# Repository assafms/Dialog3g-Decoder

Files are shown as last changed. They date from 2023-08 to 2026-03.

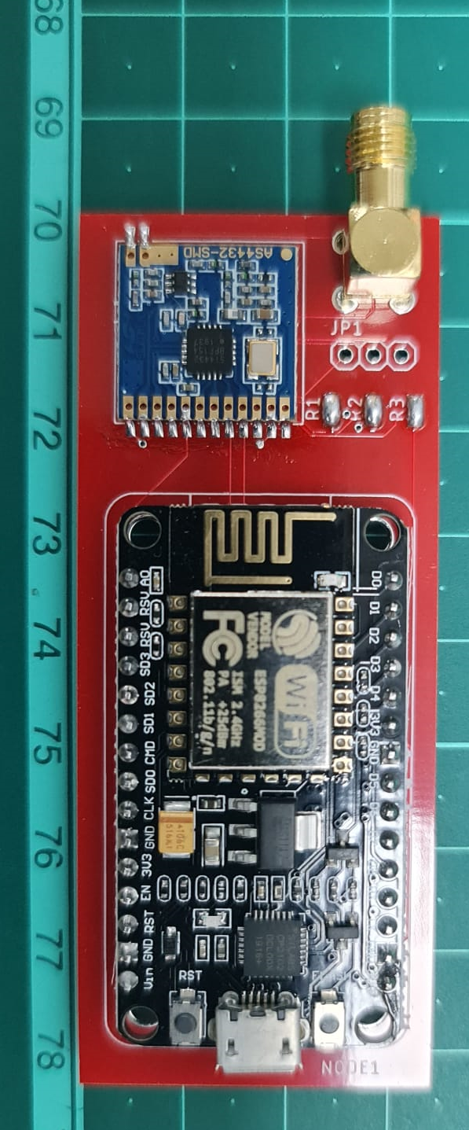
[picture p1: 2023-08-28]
PCB/completed board.png

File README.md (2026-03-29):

# Arad Dialog 3G Water Meter Decoder

ESPHome custom component and PCB for reading Arad Dialog 3G water meters using an SI4432 (XL4432) RF module and an ESP8266/ESP32.

## Overview

The Arad Dialog 3G is a water meter deployed in Israel and other countries operating at 916.3 MHz (868 MHz in some regions). This project provides:

- **Custom PCB** connecting an XL4432 module to an ESP via SPI
- **ESPHome component** that receives and decodes meter packets
- **Unified LFSR validation** for all meter groups — single model, no per-group configuration
- **3-bit error correction** — recovers packets with up to 3 corrupted bits
- **ID recovery** — corrects corrupted meter IDs using per-meter constants from validated packets

## Meter Groups

| Group | Bytes 8-9 | Cons Divisor | Notes |
|---|---|---|---|
| Standard | `0x00 0x00` | ÷10 (0.1 m³) | Residential meters |
| Sonata/x40 | `0x00 0x40` | ÷1000 (1 liter) | Commercial/street meters |
| 3D0C | `0x3D 0x0C` | ÷10 (0.1 m³) | Older model |

All groups use the same unified LFSR model with a single universal offset (`0x6FF11521E8`). No per-group detection or configuration needed — bytes 8-9 are just more data bits in the LFSR.

## How It Works

The meter transmits a 21-byte FSK/Manchester-encoded packet every ~30 seconds containing the meter ID and consumption reading. The ESPHome component validates every packet using a unified LFSR-based GF(2) model that works for all meter groups. It also applies up to 3-bit error correction to recover packets with minor RF corruption. Only validated readings are published to Home Assistant.

## Hardware

| Component | Approximate Cost |
|---|---|
| ESP8266 or ESP32 | ~$4 |
| XL4432 / SI4432 RF module | ~$2 |
| Custom PCB (see `PCB/`) or manual SPI wiring | ~$0.50 |

See `PCB/` for Eagle source files, Gerber outputs, and board photos.

## RF Parameters

| Parameter | Value |
|---|---|
| Frequency | 916.3 MHz |
| Modulation | FSK |
| Encoding | Manchester (IEEE 802.3) |
| Data Rate | 59.45 kbps |
| Frequency Deviation | 175 kHz |
| Receiver Bandwidth | 600 kHz |
| Transmission Interval | ~30 seconds |
| Preamble | 7 nibbles |
| Sync Word | `0x3E 0x69` |
| Payload | 21 bytes, fixed length, no CRC |

## Quick Start

1. Build the PCB or wire the XL4432 to the ESP via SPI (see `esphome/README.md` for pinout)
2. Copy `esphome/custom_components/xl4432_spi_sensor/` to your ESPHome `custom_components/` directory
3. Add to your YAML:

```yaml
sensor:
  - platform: xl4432_spi_sensor
    name: water_meter
    cs_pin: GPIO15
    meter_id: "0x4E61BC"
    accuracy_decimals: 1
```

4. Find your meter ID: read the decimal serial number on the meter, convert to hex. Example: decimal `5136830` → hex `0x4E61BE`. The packet transmits this big-endian.

## Packet Sniffer Mode

To capture raw packets from all nearby meters:

```yaml
sensor:
  - platform: xl4432_spi_sensor
    name: sniffer
    cs_pin: GPIO15
    meter_id: "0x000000"
    packet_sniff: true
```

All received packets are logged at INFO level. No validation or filtering is performed.

## Wireless Connection

Add `tcp_server: true` to stream packets over WiFi to the Android collector app instead of USB:

```yaml
sensor:
  - platform: xl4432_spi_sensor
    name: sniffer
    cs_pin: GPIO15
    meter_id: "0x000000"
    packet_sniff: true
    tcp_server: true
```

Enable phone hotspot, configure ESPHome WiFi with the hotspot credentials, and the Android app auto-discovers the ESP on port 4321.

## Packet Structure

| Byte(s) | Field | Description |
|---|---|---|
| 0-1 | Header | Static (`0x0A 0xEC`) |
| 2-4 | Type | Meter type / firmware variant |
| 5-7 | Meter ID | 3 bytes, big-endian |
| 8-9 | Group | `0x00 0x00` standard, `0x00 0x40` x40, `0x3D 0x0C` 3D0C |
| 10-12 | Consumption | 3 bytes, little-endian. STD/3D0C: ÷10 for m³. Sonata/x40: ÷1000 for m³ |
| 13-14 | Status | Usually `0x00 0x05` |
| 15-19 | Scramble | GF(2) integrity field |
| 20 | Trailer | High nibble only (low nibble unreliable due to Manchester timing drift) |

## GF(2) Scrambling Algorithm

Bytes 15-19 of each packet contain a 40-bit value that is a **linear function over GF(2)** of all data bytes 0-14, computed via a single 40-bit LFSR:

```
scrambled = OFFSET ^ ⨁(LFSR_vec[pos] for each set bit in bytes 0-14)
```

Where:
- **OFFSET** = `0x6FF11521E8` — universal, same for all meter groups
- All 120 basis vectors are consecutive states of a 40-bit LFSR (seed `0x51AAF3D980`, 3 feedback taps)
- Forward chain: bytes 12→11→10→9→8→7→6→5→4→3→2→1→0 (104 states)
- Backward chain: bytes 13→14 (16 states, stored as lookup)
- **^** is bitwise XOR

### Validation

Single model for all groups: compute expected scramble via LFSR from bytes 0-14, compare to received bytes 15-19. Up to 3 corrupted bits can be automatically corrected using 160 syndrome bits (120 data + 40 scramble). Achieves 80% STD, 78% x40, 83% 3D0C validation rate. See `PROTOCOL.md` for full details and basis vector tables.

## Links

- [Dialog3g-Decoder-research](https://github.com/assafms/Dialog3g-Decoder-research) — Research repo with analysis scripts, Android collector app, and detailed protocol documentation
- [rtl_433 Protocol 260](https://github.com/merbanan/rtl_433) — SDR-based decoder
- [rtl_433 Issue #1992](https://github.com/merbanan/rtl_433/issues/1992) — Original protocol analysis
- [rtl_433 Discussion #3414](https://github.com/merbanan/rtl_433/discussions/3414) — Arad Sonata analysis

## License

This project is the result of independent reverse engineering for research and interoperability purposes. Not affiliated with Arad Ltd.

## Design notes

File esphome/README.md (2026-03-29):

# ESPHome Dialog 3G Component

Custom ESPHome component for receiving and validating Arad Dialog 3G water meter transmissions using an XL4432/SI4432 RF module.

## Features

- Unified LFSR validation with up to 3-bit error correction — all meter groups, single model
- Configurable meter ID via YAML
- Packet sniffer mode for discovering meters and debugging
- Automatic low-nibble masking on byte 20 (unreliable due to Manchester timing drift)

## Installation

Copy `custom_components/xl4432_spi_sensor/` to your ESPHome config directory:

```
config/
  your_device.yaml
  custom_components/
    xl4432_spi_sensor/
      __init__.py
      sensor.py
      xl4432.cpp
      xl4432.h
      xl4432_spi_sensor.cpp
      xl4432_spi_sensor.h
```

## Configuration

```yaml
sensor:
  - platform: xl4432_spi_sensor
    name: water_meter
    cs_pin: GPIO15
    meter_id: "0x4E61BC"
    accuracy_decimals: 1
```

### Options

| Option | Required | Default | Description |
|---|---|---|---|
| `meter_id` | Yes | — | Meter ID as hex string (e.g., `"0x4E61BC"`) |
| `cs_pin` | Yes | — | SPI chip select pin |
| `packet_sniff` | No | `false` | Log all packets without filtering or publishing |
| `tcp_server` | No | `false` | Stream packets over WiFi (TCP port 4321) for the Android app |
| `accuracy_decimals` | No | `1` | Decimal places for the consumption reading |

### Finding Your Meter ID

1. Read the decimal serial number printed on the meter
2. Convert to hexadecimal
3. Reverse the byte order
4. Use in YAML config

Example: decimal `5136830` -> hex `0x4E61BE` -> reversed `0xBE614E` -> `meter_id: "0xBE614E"`

## How Validation Works

Bytes 15-19 of each packet contain a 40-bit scrambled value computed via a unified LFSR-based GF(2) linear function of all data bytes 0-14. The component computes the expected scramble and compares it to the received value. If they don't match, it attempts to correct up to 3 bit errors using syndrome matching across 160 bit positions.

- **Valid**: expected scramble matches — reading is published to Home Assistant
- **Corrected (1-3 bits)**: bit errors detected and fixed — corrected reading is published
- **Invalid**: more than 3 bit errors — packet is discarded (logged as warning)
- **ID mismatch**: packet is from a different meter — silently ignored

Works for all meter groups (STD, x40/Sonata, 3D0C) with a single universal offset. No per-group configuration needed.

## Packet Sniffer Mode

Set `packet_sniff: true` to log all received packets at INFO level without filtering or validation. Useful for:

- Discovering nearby meter IDs
- Collecting packet data for analysis
- Debugging RF reception

## Wireless Connection (TCP Server)

Set `tcp_server: true` to stream all received packets over WiFi to the Android collector app — no USB cable needed.

```yaml
sensor:
  - platform: xl4432_spi_sensor
    name: water_meter
    cs_pin: GPIO15
    meter_id: "0x93D9E9"
    packet_sniff: true
    tcp_server: true
```

Setup:
1. Enable phone hotspot
2. Configure ESPHome WiFi with the hotspot SSID and password
3. Power on the ESP — it connects to the hotspot
4. Open the Android app — it auto-discovers the ESP on port 4321

The TCP server streams packets in the same format as the serial log, so both USB and WiFi connections work with the same app.

## SPI Wiring

| ESP Pin | XL4432 Pin | Function |
|---|---|---|
| GPIO14 | SCK | SPI Clock |
| GPIO13 | SDI | SPI MOSI |
| GPIO12 | SDO | SPI MISO |
| GPIO15 | nSEL | Chip Select |
| GPIO5 | nIRQ | Interrupt |

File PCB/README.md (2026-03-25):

# PCB Design

Custom PCB connecting an XL4432 (SI4432) RF module to an ESP8266/ESP32 via SPI.

## Contents

| Directory | Description |
|---|---|
| `Eagle/` | Source schematic and board files (Eagle CAD) |
| `Gerber/` | Production-ready Gerber files (PCBWay compatible) |

## Assembly Notes

- **R1, R2, R3**: Use 0-ohm resistors or solder bridges (short the pads)
- See `schematic.png` and `pcb.png` for reference
- `completed board.png` shows an assembled example

## Bill of Materials

See `Eagle/BOM` for the full component list.

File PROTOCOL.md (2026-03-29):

# Arad Dialog 3G Water Meter — RF Protocol Reference

Reverse-engineered protocol documentation for the Arad Dialog 3G water meter (Israeli version).

> **Disclaimer**: This protocol is proprietary to Arad Ltd. This document is the result of independent reverse engineering for research and interoperability purposes. Not affiliated with Arad.

---

## 1. RF / Physical Layer

| Parameter | Value |
|---|---|
| Frequency | 916.3 MHz |
| Modulation | FSK |
| Encoding | Manchester (zero-bit variant, IEEE 802.3) |
| Data Rate | 59.45 kbps |
| Frequency Deviation  | 175 kHz |
| Receiver Bandwidth | 600 kHz |
| Transmission Interval| ~30 seconds |
| Preamble | 7 nibbles, pattern `01010` |
| Sync Word | `0x3E 0x69` |
| Payload | 21 bytes, fixed length, no CRC |

---

## 2. Packet Layout

| Byte  | Field | Notes |
|---|---|---|
| 0–1 | Static header | Always `0x0A 0xEC` |
| 2 | Header variant | Usually `0x7A`. `0x6A` seen on some meters |
| 3 | Type byte | Always `0xC8` |
| 4 | **Status / type** | `0x4B` normal. Bit 5 (`0x20`) = general alarm. Bit 7 (`0x80`) = reboot (consumption invalid). **Bit 5 feeds into scramble** |
| 5–7 | **Meter ID** | 3 bytes, big-endian (see below) |
| 8–9 | Meter group | `0x00 0x00` = standard (Group 1). `0x00 0x40` = Group 2. `0x3D 0x0C` = Group 3. Others exist (e.g. `0x0A 0x0C`) |
| 10–12 | **Consumption** | 3 bytes, little-endian, 24-bit. Divide by 10 for m³. **Invalid when byte 4 bit 7 is set (reboot)** |
| 13 | Reserved | Always `0x00` |
| 14 | **Status flags**  | Bit 3 (`0x08`) = battery OK. Bit 2 (`0x04`) = no leak (inverted: 0 = leak). Does **not** affect scramble |
| 15–19 | **Scrambled data** | GF(2) linear function of bytes 0–14 via LFSR (see §3) |
| 20 | Trailer | High nibble varies. **Low nibble unreliable** (Manchester timing drift) |

### Meter ID Encoding

The physical decimal serial number is converted to hex and transmitted **big-endian** (MSB first).

Example: serial `09444602` → hex `0x901CFA` → transmitted as bytes `90 1C FA`.

**Important**: The meter ID for the scramble algorithm uses big-endian byte order:
```
meter_id = (pkt[5] << 16) | (pkt[6] << 8) | pkt[7]
```

Note: consumption is still **little-endian**.

### Consumption

```
reading = byte[10] | (byte[11] << 8) | (byte[12] << 16)
```

The divisor depends on the meter group:
- **Standard** (bytes 8–9 = `0x00 0x00`): `volume_m3 = reading / 10.0` (0.1 m³ resolution)
- **Sonata/x40** (bytes 8–9 = `0x00 0x40`): `volume_m3 = reading / 1000.0` (1 liter resolution)
- **3D0C** (bytes 8–9 = `0x3D 0x0C`): `volume_m3 = reading / 10.0` (same as standard)

---

## 3. Scrambled Data (Bytes 15–19)

### Algorithm

Bytes 15–19 are a **linear function over GF(2)** of all data bytes 0–14, computed via a single 40-bit LFSR:

```
scrambled = OFFSET ⊕ ⨁(LFSR_vec[pos] for each set bit in bytes 0–14)
```

Where:
- `OFFSET` = `0x6FF11521E8` — universal 40-bit constant, **same for all meter groups**
- LFSR vectors are consecutive states of a 40-bit LFSR with 3 feedback taps
- `⊕` = bitwise XOR (all arithmetic is over GF(2))

### LFSR Engine

All 120 basis vectors (one per data bit in bytes 0–14) are consecutive states of a single LFSR:

```
next = (v << 1) ⊕ (TAP_A if bit 39) ⊕ (TAP_B if bit 31) ⊕ (TAP_C if bit 23)
```

| Parameter | Value |
|---|---|
| Seed | `0x51AAF3D980` (byte 12 bit 0) |
| TAP_A | `0x00014013F8` |
| TAP_B | `0x201080D890` |
| TAP_C | `0x00018F36C8` |

The forward chain runs: byte 12 → 11 → 10 → 9 → 8 → 7 → 6 → 5 → 4 → 3 → 2 → 1 → 0 (104 states).
The backward chain (LFSR inverse from seed) covers: byte 13 → 14 (16 states, stored as lookup).

The LFSR matrix has rank 39/40 (bits 0–2 are always zero), giving a 37-bit effective state.

**Important**: When byte 4 bit 7 is set (reboot alarm), the consumption field does not contain consumption data. These packets should be excluded from validation.

### Backward LFSR Vectors (Bytes 13–14)

These 16 vectors form a continuous chain with the forward LFSR. Byte 14 bit 7 connects to byte 13 bit 0 via a bridge vector, and byte 13 bit 7 connects to the seed (byte 12 bit 0).

| Byte 13 | Vector | Byte 14 | Vector |
|---|---|---|---|
| bit 0 | `0xB476FE6BB0` | bit 0 | `0x3037889DD8` |
| bit 1 | `0x68ED33F250` | bit 1 | `0x606E9E0D78` |
| bit 2 | `0xF1CAE73C30` | bit 2 | `0xC0DCB32C38` |
| bit 3 | `0xC3858185C0` | bit 3 | `0xA1A929A5D0` |
| bit 4 | `0xA71B4CF620` | bit 4 | `0x63439380C8` |
| bit 5 | `0x4E37D9FFB8` | bit 5 | `0xC686A83758` |
| bit 6 | `0x9C6E3CC9B8` | bit 6 | `0xAD1D1F9310` |
| bit 7 | `0x38DD398088` | bit 7 | `0x5A3B7F35D8` |

### Consumption Basis Vectors

LFSR positions for consumption bits 0–23 (bytes 10–12, little-endian). All groups share the same vectors.

| Bit | LFSR pos | Vector | Confidence |
|-----|---|---|---|
| 0 | 16 | `0x61B89FB6A0` | Proven |
| 1 | 17 | `0xE360308318` | Proven |
| 2 | 18 | `0xC6C12115C8` | Proven |
| 3 | 19 | `0xAD9382E0F8` | Proven |
| 4 | 20 | `0x7B374A3C50` | Proven |
| 5 | 21 | `0xF66E9478A0` | Proven |
| 6 | 22 | `0xECDDE7D470` | Proven |
| 7 | 23 | `0xF9AB805540` | Proven |
| 8 | 8 | `0xA045A72F80` | Proven |
| 9 | 9 | `0x408B817A30` | Proven |
| 10  | 10 | `0xA1060D1A38` | Proven |
| 11  | 11 | `0x420D5A2788` | Proven |
| 12  | 12 | `0x841AB44F10` | Proven |
| 13  | 13 | `0x0835A7BB10` | Proven |
| 14  | 14 | `0x106AC040E8` | Proven |
| 15  | 15 | `0x20D40FB718` | Solid |
| 16  | 0 | `0x51AAF3D980` | Proven (= LFSR seed) |
| 17  | 1 | `0x8344E85D58` | Proven (LFSR) |
| 18  | 2 | `0x06891F9F80` | Proven (LFSR) |
| 19  | 3 | `0x2D02BFE790` | Proven (LFSR) |
| 20  | 4 | `0x5A04F0F9E8` | Proven (LFSR) |
| 21  | 5 | `0xB4086EC518` | Proven (LFSR) |
| 22  | 6 | `0x68119D99C8` | Proven (LFSR) |
| 23  | 7 | `0xD022B40558` | Proven (LFSR) |

**How proven:** Bits 0–14 derived from transition analysis (ID-independent). Bit 15 from 4 standard + 1 3D0C meter. Bits 16–23 are LFSR-generated from the seed — confirmed by French researcher's independent full mask table (120/120 forward vectors match).

### Meter ID Basis Vectors

LFSR positions for meter ID bits 0–23 (bytes 5–7, big-endian). Bit 7 has zero effect on scrambling. All groups share the same vectors in the unified model.

| Bit | Vector | Confidence |
|-----|---|---|
| 0 | `0x456FF2CC60` | Proven |
| 1 | `0x8ADE6AAE08` | Proven |
| 2 | `0x0149F2DC28` | High (RANSAC 71/71) |
| 3 | `0x7FAE4CBD30` | Proven |
| 4 | `0x9694D8DA08` | Proven |
| 5 | `0x39DD1902E0` | Proven |
| 6 | `0x2E9694EEF8` | Proven |
| 7 | `0x0000000000` | Zero (unused by protocol) |
| 8 | `0x49D8C178F8` | Proven |
| 9 | `0xB3A08D1FA8` | Proven |
| 10  | `0x475155C2F0` | Proven |
| 11  | `0x8EA2AB85E0` | Proven |
| 12  | `0x3D5518F660` | Proven |
| 13  | `0x7AAA31ECC0` | Proven |
| 14  | `0xD544E30110` | Proven |
| 15  | `0xAA89092710` | Proven |
| 16  | `0x7503D28548` | Proven |
| 17  | `0xEA062A3C58` | Proven |
| 18  | `0xD40D146B48` | Proven |
| 19  | `0xA81B68C568` | Proven |
| 20  | `0x5037919928` | Proven |
| 21  | `0xA06EAC0498` | Proven |
| 22  | `0x40DD972C00` | Proven |
| 23  | `0xA1AA21B658` | Proven |

---

## 4. How to Use

### Full Validation (Recommended)

Validate any packet from any group using the unified LFSR model:

```
expected = OFFSET ⊕ ⨁(LFSR_vec[pos] for each set bit in bytes 0–14)
valid = (expected == bytes[15:19])
```

This detects RF bit errors in any of bytes 0–19. Works for **all meter groups** with a single universal offset. Error correction up to 3 bits is possible via syndrome matching (see reference implementation).

### ID Recovery

When a packet fails validation but consumption and scramble bytes are clean (only meter ID corrupted):

1. Derive constant = scrambled ⊕ LFSR_contribution(bytes 10–12)
2. Look up the constant against known validated meters
3. If found, replace bytes 5–7 with the real meter ID and re-validate

### C Implementation

See `dialog3g_validate.c` for the full reference implementation with LFSR engine, backward vectors, and 3-bit error correction. Simplified core:

```c
#include <stdint.h>

static const uint64_t LFSR_SEED  = 0x51AAF3D980ULL;
static const uint64_t LFSR_TAP_A = 0x00014013F8ULL;
static const uint64_t LFSR_TAP_B = 0x201080D890ULL;
static const uint64_t LFSR_TAP_C = 0x00018F36C8ULL;
static const uint64_t OFFSET     = 0x6FF11521E8ULL;

static uint64_t lfsr_step(uint64_t v) {
    uint64_t fb = 0;
    if (v & (1ULL << 39)) fb ^= LFSR_TAP_A;
    if (v & (1ULL << 31)) fb ^= LFSR_TAP_B;
    if (v & (1ULL << 23)) fb ^= LFSR_TAP_C;
    return ((v << 1) & 0xFFFFFFFFFFULL) ^ fb;
}

/* Backward LFSR vectors for bytes 13-14 (see §3) */
static const uint64_t BYTE13_VEC[8] = { /* ... */ };
static const uint64_t BYTE14_VEC[8] = { /* ... */ };

/* Compute expected scramble from raw packet bytes 0-14 */
uint64_t d3g_expected(const uint8_t *pkt) {
    uint64_t result = OFFSET;
    uint64_t v;
    int i;
    for (i = 0; i < 8; i++)
        if (pkt[14] & (1 << i)) result ^= BYTE14_VEC[i];
    for (i = 0; i < 8; i++)
        if (pkt[13] & (1 << i)) result ^= BYTE13_VEC[i];
    v = LFSR_SEED;
    for (i = 0; i < 104; i++) {
        if (pkt[12 - i/8] & (1 << (i%8))) result ^= v;
        v = lfsr_step(v);
    }
    return result;
}
```

### Python Implementation

See `serial_terminal/validator.py` for the full implementation. Simplified core:

```python
LFSR_SEED  = 0x51AAF3D980
LFSR_TAP_A = 0x00014013F8
LFSR_TAP_B = 0x201080D890
LFSR_TAP_C = 0x00018F36C8
OFFSET     = 0x6FF11521E8

def lfsr_step(v):
    fb = 0
    if v & (1 << 39): fb ^= LFSR_TAP_A
    if v & (1 << 31): fb ^= LFSR_TAP_B
    if v & (1 << 23): fb ^= LFSR_TAP_C
    return ((v << 1) & 0xFFFFFFFFFF) ^ fb

BYTE13_VEC = [...]  # see §3
BYTE14_VEC = [...]  # see §3

def expected(pkt):
    result = OFFSET
    for i in range(8):
        if pkt[14] & (1 << i): result ^= BYTE14_VEC[i]
    for i in range(8):
        if pkt[13] & (1 << i): result ^= BYTE13_VEC[i]
    v = LFSR_SEED
    for i in range(104):
        if pkt[12 - i // 8] & (1 << (i % 8)): result ^= v
        v = lfsr_step(v)
    return result
```

---

## 5. Confidence & Validation

| Component | Status | Evidence |
|---|---|---|
| Consumption basis (bits 0–14) | **Proven** | 370+ sequential readings, transition analysis (ID-independent) |
| Consumption basis (bit 15) | **Solid** | 4 standard meters + 1 3D0C meter (51 packets) |
| Consumption basis (bit 16) | **Proven** | = LFSR seed. Confirmed by French researcher |
| Consumption basis (bits 17–23) | **Proven** | LFSR-generated from seed. Confirmed by independent French researcher (120/120 match) |
| ID basis (bits 0–1, 4, 8–23) | **Proven** | Stable across all solves, physically verified serial numbers |
| ID basis (bits 3, 5–6) | **Proven** | Physically verified: 93D9E9 (bits 3,5,6), 082CD3 (bit 6), 5E2EE8 (bits 3,5,6) |
| ID basis (bit 2) | **High** | RANSAC 71/71 (100% for standard meters). No physical verification yet |
| ID basis (bit 7) | **Zero** | Confirmed unused by protocol |
| Full validation (unified, with 3-bit correction) | **80%** STD, **83%** 3D0C, **78%** x40 | Remaining ~20% are RF errors beyond 3-bit correction |
| ID recovery | **Proven** | Derive constant by stripping consumption, look up known meter |

### Methodology

The scrambling algorithm was reverse-engineered through a strictly non-circular process:

1. **Consumption basis (bits 0–16)**: Derived from same-meter sequential packet pairs where only the consumption changed (transition analysis). This isolates each bit's contribution with zero dependency on the ID basis. Bits 0–14 from 370+ readings. Bit 15 from 4 standard meters + 3D0C confirmation. Bit 16 from 2 meters.

2. **ID basis (RANSAC)**: Solved over 71 standard meters using RANSAC (50,000 iterations). Result: **71/71 (100%)**. One non-standard meter (134C97, bytes 8-9 = `0x0A 0x0C`) was inadvertently included and was the sole failure — confirming non-standard meters use different ID matrices. Bits 0, 1, 4 additionally constrained by physically verified meter serial numbers. Bit 7 confirmed zero.

4. **Physical verification**: 3 standard meters physically read — 93D9E9 (bits 3,5,6), 082CD3 serial 13839368 (bit 6), 5E2EE8 serial 15216222 (bits 3,5,6). Proves ID bits 3, 5, 6. Bit 2 supported by RANSAC only (no standard meter with bit 2 has been physically verified). Additionally, 1 3D0C meter physically verified (6816F9).

5. **LFSR discovery**: All 120 basis vectors (bytes 0–14) are consecutive states of a single 40-bit LFSR with 3 feedback taps. This was independently confirmed by a French researcher who solved the full mask table from a different meter population — 120/120 vectors match. The 16 backward LFSR vectors (bytes 13–14) were provided by the French research.

6. **Unified model**: With all 120 data bits in the LFSR model, a single universal offset (`0x6FF11521E8`) works for all groups (STD, x40, 3D0C). No per-group corrections needed. 3-bit error correction using 160 syndrome bits achieves 75–83% validation across all groups.

7. **Field validation**: 1303/1734 packets validate across all groups (80% STD, 78% x40, 83% 3D0C).

### Avoiding Circular Logic

Earlier iterations of this research fell into circular reasoning: using the ID basis to validate meters, then using those validated meters to confirm the ID basis. The current solution avoids this by:

- CONS_BASIS derived only from transition analysis (no ID dependency)
- Per-meter constants derived by stripping consumption from validated packets
- ID_BASIS derived only from independently confirmed constants
- CONS_BASIS bits 17+ removed until they can be derived without depending on the ID basis

### Meter Groups

| Group | Bytes 8–9 | Cons Divisor | Pass Rate (with 3-bit correction) |
|---|---|---|---|
| Standard | `0x00 0x00` | ÷10 (0.1 m³) | 80.0% (984/1230) |
| Sonata/x40 | `0x00 0x40` | ÷1000 (1 liter) | 77.6% (190/245) |
| 3D0C | `0x3D 0x0C` | ÷10 (0.1 m³) | 83.1% (98/118) |
| Other | Various | — | 22.0% (likely RF bit-flips of known groups) |

All groups use the **same universal LFSR model and offset** (`0x6FF11521E8`). Bytes 8–9 are just more data bits in the LFSR — no per-group detection or offset selection needed.

3D0C meters appear to be an older model. x40 meters are **Arad Sonata** ultrasonic meters — typically commercial/street installations. They report consumption in liters (÷1000 for m³) rather than 0.1 m³ units (÷10). Physically verified: FA7509 (serial 620026) reads 2148.253 m³ = raw 2148253. Standard meters are residential Dialog 3G models.

---

## 6. Known Limitations

- **Bytes 0–4**: Included in the LFSR model. Bytes 0–3 are static header, byte 4 has status flags. All feed into the scramble via pure LFSR.
- **Bytes 13–14**: Backward LFSR vectors provided by French research. Byte 13 is typically `0x00`. Byte 14 carries status flags (battery, leak).
- **Byte 20**: Low nibble unreliable due to Manchester timing drift. Should be masked to `& 0xF0`.
- **~20% failure rate**: Remaining invalid packets are RF errors beyond 3-bit correction capability.
- **Regional variants**: Only tested on Israeli version (916.3 MHz). A French researcher has independently confirmed the same LFSR on their meters. US/European versions may use different frequencies and/or different basis vectors.

---

## 7. References

- [Dialog3g-Decoder](https://github.com/assafms/Dialog3g-Decoder) — ESPHome + SI4432 hardware implementation
- [rtl_433](https://github.com/merbanan/rtl_433) — SDR decoder (Protocol 260, decodes ID + consumption but not scrambled bytes)
- [rtl_433 Issue #1992](https://github.com/merbanan/rtl_433/issues/1992) — Original protocol analysis
- [rtl_433 Discussion #3414](https://github.com/merbanan/rtl_433/discussions/3414) — Arad Sonata analysis

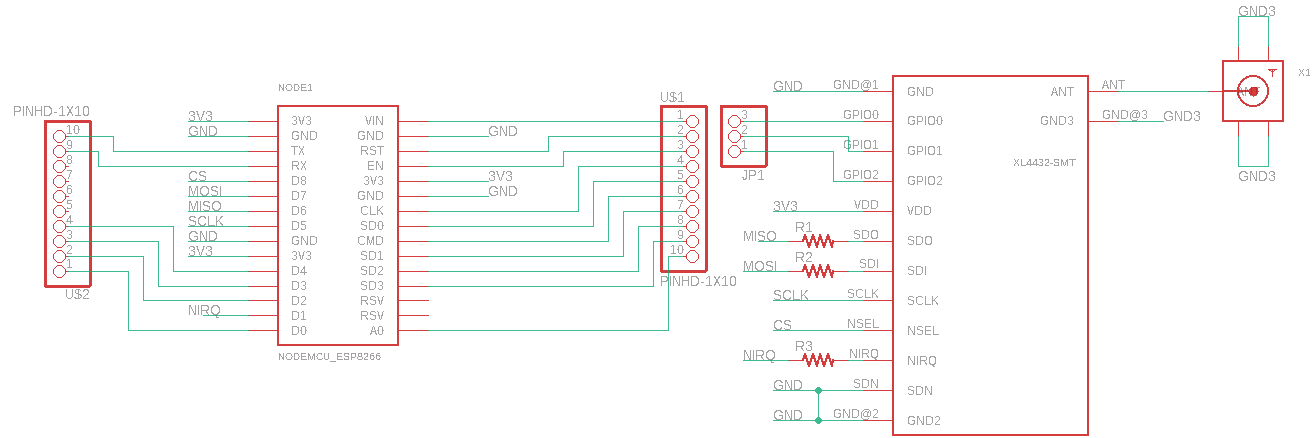
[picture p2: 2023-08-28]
PCB/schematic.png

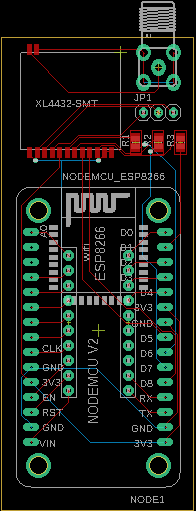
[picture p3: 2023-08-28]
PCB/pcb.png

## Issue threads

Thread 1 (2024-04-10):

Code

fc0ta, 2024-04-10:
Hello! Thanks for posting your finds on how to read the Arad meters.  Are you releasing the Arduino code? Does a board exists with 3G/4G instead of wifi? Have a great day

fc0ta, 2024-04-10:
Thank your for your prompt response, appreciated.

Closed 2024-04-10.

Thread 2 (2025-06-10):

Question about soldering the pcb

idiamant, 2025-06-10:
Hey,

A friend has ordered the PCB and all of the required parts to solder to it.

About soldering the nodemcu and the chip, its easy to understand. I want to make sure if any soldering is required in the middle two row 10 pins, under the nodemcu module? Or if its there just in case I want to connect to the nodemcu other equipment in parallel?

Also, how did you run the built board, with regards to power input? Using USB or did you connect to the VIN/Gnd?

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

idiamant, 2025-06-12:
Tested with multi-meter, and saw the inner pins are connected to some of the other pins externally, so I have proceeded with soldering.

Closed 2025-06-12.

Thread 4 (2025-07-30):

Cannot dtct my meter

drorya1, 2025-07-30:
Hi Assaf
I used all the valuable info you provided and have a "so called" working project .
I added the integration and I get packets from the baord , yet niether are of my meter .
I tried to sniff my neighbour meter as well yet I get packets with Unknown Packet and long streams
After few days of testing I reachd a dead nd where I dont know if the configuration should b changed? or maybe the board does not function as it should.
Cnfiguration for yaml file is below
esp8266:
  board: nodemcuv2

# Enable logging
logger:

# Enable Home Assistant API
api:
  encryption:
    key: "XXXXXXASsBu8LkkvoVecXXXXXXX"

ota:
  - platform: esphome
    password: "XXXXXX594faf0d94XXXXXX"

wifi:
  ssid: "24_I"
  password: "password"

  manual_ip:
    static_ip: 192.168.0.170
    gateway: 192.168.0.1
    subnet: 255.255.255.0
  # Enable fallback hotspot (captive portal) in case wifi connection fails
  ap:
    ssid: "Water-Meter Fallback Hotspot"
    password: "XXXXXehiTTE"

external_components:
  - source: custom_components

spi:
  clk_pin: GPIO14
  miso_pin: GPIO12
  mosi_pin: GPIO13

sensor:
  - platform: xl4432_spi_sensor
    name: Water Meter
    cs_pin: GPIO15
    meter_id: "0xD670G4"
    update_interval: 60s

mqtt:
  broker: "192.168.0.4"
  username: "mqtt_user"
  password: "mqttpass"

Example log from the device :

INFO ESPHome 2025.7.4
INFO Reading configuration /config/esphome/water-meter.yaml...
INFO Starting log output from 192.168.0.170 using esphome API
INFO Successfully resolved water-meter @ 192.168.0.170 in 0.000s
INFO Successfully connected to water-meter @ 192.168.0.170 in 0.008s
INFO Successful handshake with water-meter @ 192.168.0.170 in 2.435s
[21:39:18][I][app:149]: ESPHome version 2025.7.4 compiled on Jul 30 2025, 10:49:22
[21:39:18][C][wifi:613]: WiFi:
[21:39:18][C][wifi:434]:   Local MAC: 40:F5:20:33:B6:9F
[21:39:18][C][wifi:439]:   SSID: [redacted]
[21:39:18][C][wifi:442]:   IP Address: 192.168.0.170
[21:39:18][C][wifi:446]:   BSSID: [redacted]
[21:39:18][C][wifi:446]:   Hostname: 'water-meter'
[21:39:18][C][wifi:446]:   Signal strength: -78 dB ▂▄▆█
[21:39:18][C][wifi:455]:   Channel: 9
[21:39:18][C][wifi:455]:   Subnet: 255.255.255.0
[21:39:18][C][wifi:455]:   Gateway: 192.168.0.1
[21:39:18][C][wifi:455]:   DNS1: 0.0.0.0
[21:39:18][C][wifi:455]:   DNS2: 0.0.0.0
[21:39:18][C][logger:246]: Logger:
[21:39:18][C][logger:246]:   Max Level: DEBUG
[21:39:18][C][logger:246]:   Initial Level: DEBUG
[21:39:18][C][logger:252]:   Log Baud Rate: 115200
[21:39:18][C][logger:252]:   Hardware UART: UART0
[21:39:18][C][spi:069]: SPI bus:
[21:39:18][C][spi:070]:   CLK Pin: GPIO14
[21:39:18][C][spi:071]:   SDI Pin: GPIO12
[21:39:18][C][spi:072]:   SDO Pin: GPIO13
[21:39:18][C][spi:077]:   Using HW SPI: SPI
[21:39:18][C][xl4432_spi_sensor.sensor:114]: Xl4432 SPI sensor
[21:39:18][C][esphome.ota:073]: Over-The-Air updates:
[21:39:18][C][esphome.ota:073]:   Address: 192.168.0.170:8266
[21:39:18][C][esphome.ota:073]:   Version: 2
[21:39:18][C][esphome.ota:080]:   Password configured
[21:39:18][C][safe_mode:018]: Safe Mode:
[21:39:18][C][safe_mode:019]:   Boot considered successful after 60 seconds
[21:39:18][C][safe_mode:019]:   Invoke after 10 boot attempts
[21:39:18][C][safe_mode:019]:   Remain for 300 seconds
[21:39:18][C][api:207]: API Server:
[21:39:18][C][api:207]:   Address: 192.168.0.170:6053
[21:39:18][C][api:212]:   Using noise encryption: YES
[21:39:18][C][mqtt:155]: MQTT:
[21:39:18][C][mqtt:155]:   Server Address: 192.168.0.4:1883 (192.168.0.4)
[21:39:18][C][mqtt:155]:   Username: [redacted]
[21:39:18][C][mqtt:155]:   Client ID: [redacted]
[21:39:18][C][mqtt:155]:   Clean Session: NO
[21:39:18][C][mqtt:165]:   Discovery IP enabled
[21:39:18][C][mqtt:168]:   Discovery prefix: 'homeassistant'
[21:39:18][C][mqtt:168]:   Discovery retain: YES
[21:39:18][C][mqtt:173]:   Topic Prefix: 'water-meter'
[21:39:18][C][mqtt:175]:   Log Topic: 'water-meter/debug'
[21:39:18][C][mqtt:178]:   Availability: 'water-meter/status'
[21:39:18][C][mdns:122]: mDNS:
[21:39:18][C][mdns:122]:   Hostname: water-meter
[21:39:18][C][mqtt.sensor:028]: MQTT Sensor 'Water Meter':
[21:39:18][C][mqtt.sensor:032]:   State Topic: 'water-meter/sensor/water_meter/state'
[21:39:23][D][custom:107]: Unknown Packet:0AEC7AC84B1A1592C7047A1300000530D0773910FC
[21:39:53][D][custom:107]: Unknown Packet:0AEC7AC84B1A1592C7047A1300000530D077B910FF
[21:40:07][D][custom:107]: Unknown Packet:0AEC7AC84BEA4197C704D6750000056339E99340FF
[21:40:23][D][custom:107]: Unknown Packet:0AEC7AC84B1A1592C7047A1300000530D075B910FC
[21:40:37][D][custom:107]: Unknown Packet:0AEC7AC84BEA4197C704D6750000056339E99340FF
[21:40:53][D][custom:107]: Unknown Packet:0AEC7AC84B1A1592C7047A1300000530D077B910FF

Any insights would be highly appreciated .
Dror
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
assafms, 2025-08-10:
you can improve the SNR and use some more gain . but this is not the problem . the rtart of the signal makes no sense.

assafms, 2025-08-10:
Found your meter in the message. The start of the signal is total garbage, and most of the preamble is gone.
But there are a few bits left, and then the message :

11111 1111 1000 0110 1001 0000 1010 1110 1100 0110 0010 1100 1000 0100 1011 1101 0110 0111 0000 rest of it (has the correct meter reading) ->
1111001100000000000000000111101001001110000000000000011111110100100100100101011010010110011000100000011

This translates to :
f8 69 0a ec 62 c8 4b d6 70 F3 ..... this is your meter

The regular signal uses a long preamble, 3E 69 as the sync word. 0A EC starts the frame, three unknown bytes, and then the meter number. in your case , the preamble is horrible , the sync I got was f8 69 and then the rest is the same.
We can try to set the preamble length to minimum and the sync to f8 69 and hope for the best. But I do believe something is wrong with your meter. maybe the battery is dead , maybe something else.

if you want to try :  Replace initXl4432Registers with this code and hope for the best.

void Xl4432::initXl4432Registers()
{
  spiDisableReciver();
  spiXl4432Fifo();
  spiWriteRegister(0x1C, 0x8C);
  spiWriteRegister(0x1D, 0x00);
  spiWriteRegister(0x20, 0x65);
  spiWriteRegister(0x21, 0x00);
  spiWriteRegister(0x22, 0xA2);
  spiWriteRegister(0x23, 0x57);
  spiWriteRegister(0x24, 0x00);
  spiWriteRegister(0x25, 0xDE);
  spiWriteRegister(0x30, 0xA8);
  spiWriteRegister(0x32, 0x8C);
  spiWriteRegister(0x33, 0x0A);
  spiWriteRegister(0x34, 0x01);  //preamble of just 4bits for the strange meter Dror has
  spiWriteRegister(0x35, 0x3A);
  spiWriteRegister(0x36, 0xf8);  // first sync for Dror
  spiWriteRegister(0x37, 0x69);  // second sync
  spiWriteRegister(0x3E, 0x28);  //length of packet
  spiWriteRegister(0x6E, 0x01);
  spiWriteRegister(0x6F, 0x3B);
  spiWriteRegister(0x70, 0x22);  //invert manchester?
  spiWriteRegister(0x71, 0x26);
  spiWriteRegister(0x72, 0x18);
  spiWriteRegister(0x75, 0x75);
  spiWriteRegister(0x76, 0xCB);
  spiWriteRegister(0x77, 0xC0);
  spiWriteRegister(0x0b, 0x14);  // GPIO0 RX Data
  spiWriteRegister(0x0C, 0x19);  // GPIO1 Valid preamble
  spiWriteRegister(0x0D, 0x0F);  // GPIO2
  spiEnableReciver();
}

assafms, 2025-08-10:
I don't think more recordings will help. The signal is bad at the source.
Change the function in the code (in your ESPhome directory) and reinstall the firmware. It may work.

drorya1, 2025-08-11:
Tried changing it with assistance of Chatgpt ,
No packets recieved after the change .
Will look deeper to see if I did it correct 😔
Will update after I will validate the changes
Thx

drorya1, 2025-08-13:
Hi
Found it and replaced yet I do not see any packets decoded
This is how it looks like

[08:16:25][C][mqtt:155]:   Clean Session: NO
[08:16:25][C][mqtt:165]:   Discovery IP enabled
[08:16:25][C][mqtt:168]:   Discovery prefix: 'homeassistant'
[08:16:25][C][mqtt:168]:   Discovery retain: YES
[08:16:25][C][mqtt:173]:   Topic Prefix: 'watermeter'
[08:16:25][C][mqtt:175]:   Log Topic: 'watermeter/debug'
[08:16:25][C][mqtt:178]:   Availability: 'watermeter/status'
[08:16:25][C][mdns:122]: mDNS:
[08:16:25][C][mdns:122]:   Hostname: watermeter
[08:16:25][C][mqtt.sensor:028]: MQTT Sensor 'xl4432':
[08:16:25][C][mqtt.sensor:032]:   State Topic: 'watermeter/sensor/xl4432/state'

From GPT answer I get the following answer
WDYT ?

Given your current radio config you’re doing a fairly strict experiment:

Preamble = 4 bits (0x34=0x01) and sync = F8 69 only.

HW packet length = 22 bytes, matching your software buffers (good).

The ISR disables RX, checks the status, and only reads the FIFO on VALID_PACKET. If the chip never asserts VALID_PACKET, you’ll never see any of your packet logs.

With a weak/garbled preamble (like your earlier captures suggested), a 4‑bit preamble plus a 2‑byte sync might be too tight to acquire reliably—hence no interrupts.

Fastest next steps to get any packets again
Try these in order (one change at a time):

Add the next two sync bytes you often see (0A EC)
In initXl4432Registers() right after 0x37:

cpp
Copy
Edit
spiWriteRegister(0x38, 0x0A);
spiWriteRegister(0x39, 0xEC);
This keeps F8 69 but gives the chip more to latch onto.

If still silent, lengthen preamble a bit
Change 0x34 from 0x01 to 0x03 (or back to your original 0x07):

cpp
Copy
Edit
spiWriteRegister(0x34, 0x03);
That relaxes acquisition for a weak TX.

If still
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

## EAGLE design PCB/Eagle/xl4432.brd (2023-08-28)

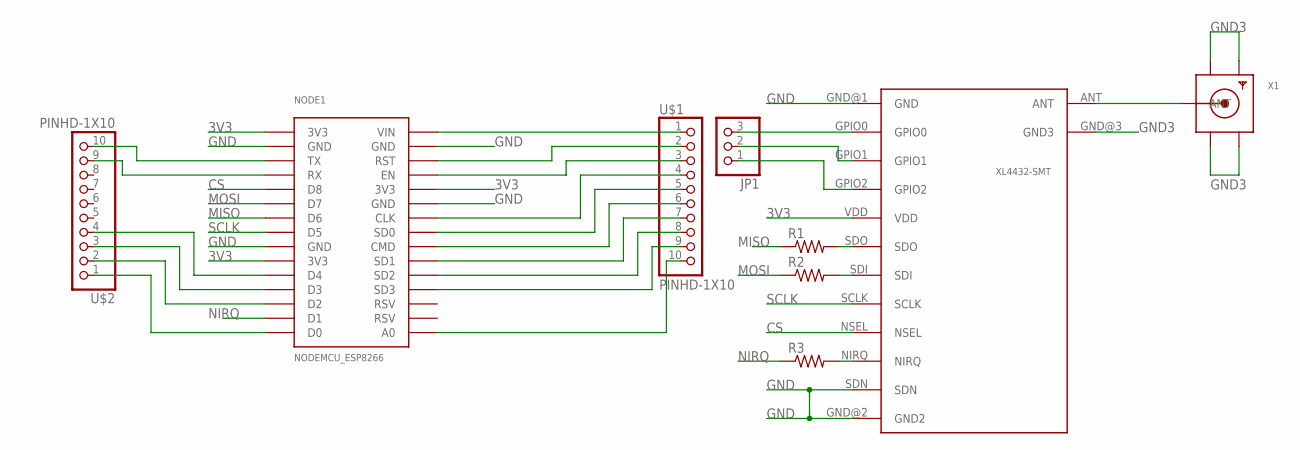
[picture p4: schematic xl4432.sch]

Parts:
4332-1: XM4432-SMT; XL4432-SMT
JP1: PINHD-1X3; 1X03
NODE1: NODEMCU_ESP8266
R1, R2, R3: R-US_R2012; R2012
U$1, U$2: PINHD-1X10; 1X10-BIG
X1: SMACONNECTOR; SMA90_DIP

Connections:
3V3: 4332-1.VDD, NODE1.3V3@1 (3V3), NODE1.3V3@2 (3V3), NODE1.3V3@3 (3V3)
CS: 4332-1.NSEL, NODE1.D8
GND: 4332-1.GND@1 (GND), 4332-1.GND@2 (GND2), 4332-1.SDN, NODE1.GND@1 (GND), NODE1.GND@2 (GND), NODE1.GND@3 (GND), NODE1.GND@4 (GND)
GND3: 4332-1.GND@3 (GND3), X1.GND1, X1.GND2, X1.GND3, X1.GND4
MISO: NODE1.D6, R1.1
MOSI: NODE1.D7, R2.1
unnamed: 4332-1.ANT, X1.ANTENNA (ANT)
unnamed: 4332-1.GPIO0, JP1.3
unnamed: 4332-1.GPIO1, JP1.2
unnamed: 4332-1.GPIO2, JP1.1
unnamed: NODE1.VIN, U$1.1
unnamed: NODE1.RST, U$1.2
unnamed: NODE1.EN, U$1.3
unnamed: NODE1.CLK, U$1.4
unnamed: NODE1.SDO (SD0), U$1.5
unnamed: NODE1.CMD, U$1.6
unnamed: NODE1.SD1, U$1.7
unnamed: NODE1.SD2, U$1.8
unnamed: NODE1.SD3, U$1.9
unnamed: NODE1.A0, U$1.10
unnamed: NODE1.TX, U$2.10
unnamed: NODE1.RX, U$2.9
unnamed: NODE1.D0, U$2.1
unnamed: NODE1.D2, U$2.2
unnamed: NODE1.D3, U$2.3
unnamed: NODE1.D4, U$2.4
unnamed: 4332-1.SDO, R1.2
unnamed: 4332-1.SDI, R2.2
unnamed: 4332-1.NIRQ, R3.2
NIRQ: NODE1.D1, R3.1
SCLK: 4332-1.SCLK, NODE1.D5

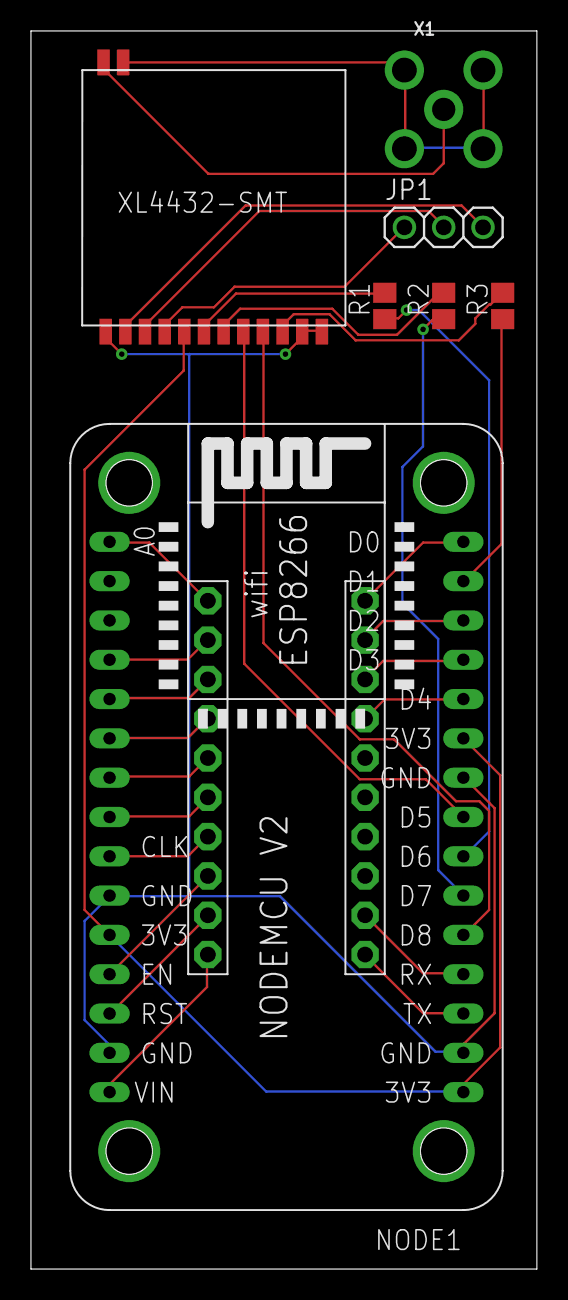
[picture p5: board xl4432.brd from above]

Board: 2 copper layers, 32.7 x 80.0 mm, 9 parts (0 on the bottom side), 31 nets.

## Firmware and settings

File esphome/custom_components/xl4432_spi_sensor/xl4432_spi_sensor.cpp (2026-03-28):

#include "esphome/core/log.h"
#include "xl4432_spi_sensor.h"
#include "xl4432.h"
#include <string>
#include <vector>
#include <algorithm>

namespace esphome {
namespace xl4432_spi_sensor {

static const char *TAG = "xl4432_spi_sensor.sensor";
#define nIRQ_PIN     5

char  METER_ID[]= {0x12,0x34,0x56};

bool PACKET_SNIFF = false;
Xl4432 xl4432(METER_ID);

void Xl4432SPISensor::set_meter_id(const std::string &meter_id) {
  std::string id_str = meter_id;
  id_str.erase(std::remove(id_str.begin(), id_str.end(), ' '), id_str.end());
  std::transform(id_str.begin(), id_str.end(), id_str.begin(), ::toupper);
  if (id_str.substr(0, 2) == "0X") {
    id_str = id_str.substr(2);
  }
  if (id_str.length() == 6) {
    bool valid_hex = true;
    for (char c : id_str) {
      if (!((c >= '0' && c <= '9') || (c >= 'A' && c <= 'F'))) {
        valid_hex = false;
        break;
      }
    }
    if (valid_hex) {
      uint32_t full_id = std::stoul(id_str, nullptr, 16);
      METER_ID[0] = (char)((full_id >> 16) & 0xFF);
      METER_ID[1] = (char)((full_id >> 8) & 0xFF);
      METER_ID[2] = (char)(full_id & 0xFF);
      xl4432 = Xl4432(METER_ID);
    } else {
      ESP_LOGW(TAG, "Invalid hex characters in meter_id, using default");
    }
  } else {
    ESP_LOGW(TAG, "Invalid meter_id format, using default");
  }
}

void Xl4432SPISensor::set_packet_sniff(bool packet_sniff) {
  PACKET_SNIFF = packet_sniff;
  xl4432.packetSniff = packet_sniff;
}

void Xl4432SPISensor::set_tcp_server(bool enabled) {
  tcp_enabled_ = enabled;
}

IRAM_ATTR void nIRQ_ISR(){
  xl4432.spiDisableReciver();
  xl4432.checkForNewPacket();
  xl4432.spiEnableReciver();
}

void Xl4432SPISensor::setup() {
    pinMode(SS, OUTPUT);
    digitalWrite(SS, HIGH);
    pinMode(nIRQ_PIN, INPUT);
    attachInterrupt(nIRQ_PIN, nIRQ_ISR, FALLING);
    xl4432.initXl4432Registers();
    xl4432.lastMeterMeasurment = 0;
#ifdef USE_ARDUINO
    if (tcp_enabled_) {
        tcp_server_.begin();
        ESP_LOGI(TAG, "TCP sniff server on port %d", SNIFF_TCP_PORT);
    }
#endif
}

void Xl4432SPISensor::send_to_clients(const char *line) {
#ifdef USE_ARDUINO
    if (!tcp_enabled_) return;
    // Send to all connected clients
    for (int i = 0; i < 3; i++) {
        if (tcp_clients_[i] && tcp_clients_[i].connected()) {
            tcp_clients_[i].print(line);
            tcp_clients_[i].print("\n");
        }
    }
#endif
}

void Xl4432SPISensor::update() {
}

void Xl4432SPISensor::loop() {

#ifdef USE_ARDUINO
if (tcp_enabled_) {
    WiFiClient newClient = tcp_server_.available();
    if (newClient) {
        for (int i = 0; i < 3; i++) {
            if (!tcp_clients_[i] || !tcp_clients_[i].connected()) {
                tcp_clients_[i] = newClient;
                ESP_LOGI(TAG, "TCP client %d connected", i);
                break;
            }
        }
    }
}
#endif

if (!xl4432.packetReady)
    return;

xl4432.packetReady = 0;

if (PACKET_SNIFF) {
    char tcp_line[64];
    snprintf(tcp_line, sizeof(tcp_line), "[sniff:916300000]: %s", xl4432.output);
    send_to_clients(tcp_line);
    ESP_LOGI("sniff", "%s", xl4432.output);
    return;
}

PacketStatus status = xl4432.validatePacket();
stat_total_++;

// Tag: OK, F1/F2/F3 (fixed), BAD, 2PK, NS, or other
const char *tag = "??";
switch (status) {
    case PKT_VALID:
        tag = "OK";
        stat_valid_++;
        publish_state(xl4432.meterMeasurment);
        break;

    case PKT_CORRECTED_1:
    case PKT_CORRECTED_2:
    case PKT_CORRECTED_3: {
        int nbits = status - PKT_CORRECTED_1 + 1;
        stat_corrected_[nbits - 1]++;
        xl4432.meterMeasurment = xl4432.extractMeterReading();
        xl4432.binToHexString();  // update output with corrected packet
        publish_state(xl4432.meterMeasurment);
        tag = nbits == 1 ? "F1" : nbits == 2 ? "F2" : "F3";
        break;
    }

    case PKT_INVALID:
        tag = "BAD";
        stat_invalid_++;
        break;

    case PKT_ID_MISMATCH:
        ESP_LOGD("gf2", "Other meter: %s", xl4432.output);
        goto skip_log;

    case PKT_VALID_TWO_PKT:
        tag = "2PK";
        stat_valid_++;
        publish_state(xl4432.meterMeasurment);
        break;

    case PKT_NON_STANDARD:
        tag = "NS";
        break;

    default:
        break;
}

{
    char tcp_line[80];
    snprintf(tcp_line, sizeof(tcp_line), "[sniff:916300000]: %s", xl4432.output);
    send_to_clients(tcp_line);
    ESP_LOGI("gf2", "[%s] reading=%.1f pkt=%s", tag, xl4432.meterMeasurment, xl4432.output);
}
skip_log:

// Log stats every 10 packets
if (stat_total_ > 0 && stat_total_ % 10 == 0) {
    uint32_t corrected = stat_corrected_[0] + stat_corrected_[1] + stat_corrected_[2];
    ESP_LOGI("stats", "Pkts=%lu Valid=%lu Fix1=%lu Fix2=%lu Fix3=%lu Bad=%lu (%.0f%% ok)",
             stat_total_, stat_valid_,
             stat_corrected_[0], stat_corrected_[1], stat_corrected_[2],
             stat_invalid_,
             100.0 * (stat_valid_ + corrected) / stat_total_);
}

}

void Xl4432SPISensor::dump_config(){
    ESP_LOGCONFIG(TAG, "Xl4432 SPI sensor");
}

}  // namespace xl4432_spi_sensor
}  // namespace esphome

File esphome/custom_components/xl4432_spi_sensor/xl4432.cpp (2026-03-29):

#include "esphome/core/log.h"
#include "xl4432_spi_sensor.h"
#include "xl4432.h"

// 40-bit LFSR with 3 feedback taps — generates all basis vectors
// Forward chain: bytes 12→11→10→9→8→7→6→5→4→3→2→1→0 (104 states)
// Backward chain: bytes 13→14 (16 states, stored as lookup)
static const uint64_t LFSR_SEED  = 0x51AAF3D980ULL;
static const uint64_t LFSR_TAP_A = 0x00014013F8ULL;
static const uint64_t LFSR_TAP_B = 0x201080D890ULL;
static const uint64_t LFSR_TAP_C = 0x00018F36C8ULL;

// Backward LFSR vectors (bytes 13-14, from French research)
static const uint64_t BYTE13_VEC[8] = {
	0xB476FE6BB0ULL, 0x68ED33F250ULL, 0xF1CAE73C30ULL, 0xC3858185C0ULL,
	0xA71B4CF620ULL, 0x4E37D9FFB8ULL, 0x9C6E3CC9B8ULL, 0x38DD398088ULL
};
static const uint64_t BYTE14_VEC[8] = {
	0x3037889DD8ULL, 0x606E9E0D78ULL, 0xC0DCB32C38ULL, 0xA1A929A5D0ULL,
	0x63439380C8ULL, 0xC686A83758ULL, 0xAD1D1F9310ULL, 0x5A3B7F35D8ULL
};

// Universal offset — same for all meter groups
static const uint64_t OFFSET = 0x6FF11521E8ULL;

// Syndrome table sizes: 120 data + 40 scramble = 160
static const int NUM_DATA  = 120;
static const int NUM_TOTAL = 160;

Xl4432::Xl4432(char id[3], bool use_id_as_sync)
{
	nIRQState = 0;
	meterMeasurment = -1;
	packetReady = 0;
	lastMeterMeasurment = 0;
	storedConstant = 0;
	hasStoredConstant = false;
	METER_ID[0] = id[0];
	METER_ID[1] = id[1];
	METER_ID[2] = id[2];
	useIdAsSync = use_id_as_sync;
	packetSniff = false;
}

static uint64_t lfsr_next(uint64_t v)
{
	uint64_t fb = 0;
	if (v & (1ULL << 39)) fb ^= LFSR_TAP_A;
	if (v & (1ULL << 31)) fb ^= LFSR_TAP_B;
	if (v & (1ULL << 23)) fb ^= LFSR_TAP_C;
	return ((v << 1) & 0xFFFFFFFFFFULL) ^ fb;
}

uint64_t Xl4432::expectedScramble()
{
	uint64_t result = OFFSET;

	// Byte 14 (backward LFSR)
	for (int i = 0; i < 8; i++)
		if (packet[14] & (1 << i)) result ^= BYTE14_VEC[i];

	// Byte 13 (backward LFSR)
	for (int i = 0; i < 8; i++)
		if (packet[13] & (1 << i)) result ^= BYTE13_VEC[i];

	// Bytes 12 down to 0 (forward LFSR, 104 bits)
	uint64_t v = LFSR_SEED;
	for (int i = 0; i < 104; i++) {
		if (packet[12 - i/8] & (1 << (i%8)))
			result ^= v;
		v = lfsr_next(v);
	}

	return result;
}

uint64_t Xl4432::deriveConstant()
{
	uint64_t actual = ((uint64_t)packet[15] << 32) | ((uint64_t)packet[16] << 24) |
	                  ((uint64_t)packet[17] << 16) | ((uint64_t)packet[18] << 8) |
	                  (uint64_t)packet[19];
	uint64_t result = actual;

	// Strip consumption contribution (bytes 12, 11, 10 = 24 LFSR states)
	uint64_t v = LFSR_SEED;
	for (int i = 0; i < 24; i++) {
		if (packet[12 - i/8] & (1 << (i%8)))
			result ^= v;
		v = lfsr_next(v);
	}

	return result;
}

static void idx_to_pos(int idx, int *bp, int *bi)
{
	if (idx < 8) {
		*bp = 14; *bi = idx;
	} else if (idx < 16) {
		*bp = 13; *bi = idx - 8;
	} else if (idx < 120) {
		int k = idx - 16;
		*bp = 12 - k/8;
		*bi = k % 8;
	} else {
		int s = idx - 120;
		*bp = 19 - s/8;
		*bi = s % 8;
	}
}

PacketStatus Xl4432::validatePacket()
{
	if (packetSniff)
		return PKT_SNIFF;

	bool idMatch;
	if (useIdAsSync) {
		idMatch = true;
	} else {
		idMatch = (packet[5] == METER_ID[0] &&
		           packet[6] == METER_ID[1] &&
		           packet[7] == METER_ID[2]);
	}
	if (!idMatch)
		return PKT_ID_MISMATCH;

	// Skip reboot packets (byte 4 bit 7) — consumption field is invalid
	if (packet[4] & 0x80)
		return PKT_NON_STANDARD;

	// Unified validation: pure LFSR, all bytes 0-14, all groups
	uint64_t expected = expectedScramble();
	uint64_t actual = ((uint64_t)packet[15] << 32) | ((uint64_t)packet[16] << 24) |
	                  ((uint64_t)packet[17] << 16) | ((uint64_t)packet[18] << 8) |
	                  (uint64_t)packet[19];
	uint64_t syndrome = expected ^ actual;

	if (syndrome == 0)
		return PKT_VALID;

	// Build syndrome table: 16 backward + 104 forward + 40 scramble = 160
	uint64_t syn[NUM_TOTAL];
	for (int i = 0; i < 8; i++) syn[i] = BYTE14_VEC[i];
	for (int i = 0; i < 8; i++) syn[8 + i] = BYTE13_VEC[i];
	uint64_t v = LFSR_SEED;
	for (int i = 0; i < 104; i++) { syn[16 + i] = v; v = lfsr_next(v); }
	for (int i = 0; i < 40; i++) syn[120 + i] = 1ULL << i;

	auto flip = [&](int idx) {
		int bp, bi;
		idx_to_pos(idx, &bp, &bi);
		packet[bp] ^= (1 << bi);
	};

	// 1-bit correction
	for (int i = 0; i < NUM_TOTAL; i++) {
		if (syn[i] == syndrome) {
			flip(i);
			return PKT_CORRECTED_1;
		}
	}

	// 2-bit correction
	for (int i = 0; i < NUM_TOTAL; i++) {
		uint64_t r1 = syndrome ^ syn[i];
		for (int j = i+1; j < NUM_TOTAL; j++) {
			if (syn[j] == r1) {
				flip(i); flip(j);
				return PKT_CORRECTED_2;
			}
		}
	}

	// 3-bit correction (~680K iterations worst case)
	for (int i = 0; i < NUM_TOTAL; i++) {
		uint64_t r1 = syndrome ^ syn[i];
		for (int j = i+1; j < NUM_TOTAL; j++) {
			uint64_t r2 = r1 ^ syn[j];
			for (int k = j+1; k < NUM_TOTAL; k++) {
				if (syn[k] == r2) {
					flip(i); flip(j); flip(k);
					return PKT_CORRECTED_3;
				}
			}
		}
	}

	return PKT_INVALID;
}

float Xl4432::extractMeterReading()
{
	if (useIdAsSync) {
		return float((packet[3] << 16) + (packet[2] << 8) + packet[1]) / 10;
	} else {
		float raw = float((packet[12] << 16) + (packet[11] << 8) + packet[10]);
		// Sonata/x40 meters report in liters, standard in 0.1 m³
		return (packet[9] == 0x40) ? raw / 1000 : raw / 10;
	}
}

void Xl4432::readPacketFromFifo()
{
	spiWriteRegister(0x07, 0x01);
	spiReadPacketFromFifo(PACKET_SIZE);
	spiWriteRegister(0x08, 0x02);
	spiWriteRegister(0x08, 0x00);
	spiWriteRegister(0x07, 0x05);
}

void Xl4432::spiInitRadio()
{
	spiWriteRegister(0x07, 0x80);
	delay(100);
	spiReadRegister(0x03);
	spiReadRegister(0x04);
	delay(100);
}

void Xl4432::spiDisableReciver()
{
	spiWriteRegister(0x07, 0x01);
}

void Xl4432::spiEnableReciver()
{
	spiWriteRegister(0x07, 0x05);
	spiWriteRegister(0x05, 0x03);
	spiWriteRegister(0x06, 0x00);
	spiReadRegister(0x03);
	spiReadRegister(0x04);
}
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

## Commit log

2023-08-28 Initial commit
    Initial commit
    [xl4432.brd, xl4432.sch]
2025-06-18 Debug and Raw sniffing
    Added the ability to sniff any meter id .
    Added Syslog
    Better check for the packet to prevent errors as we dont have a CRC
    [xl4432.cpp, xl4432_spi_sensor.cpp]
2026-03-21 Add sync mode option to use meter ID as sync words
    Allows the radio to use the meter ID as part of the 4-byte sync word
    sequence, improving packet filtering at the hardware level. When enabled,
    preamble detection is skipped and the meter reading is extracted from
    earlier packet bytes since the ID is consumed by sync matching.
    [xl4432.cpp]
2026-03-21 Replace custom syslog with native ESPHome syslog component
    Remove the deprecated custom syslog component (TheStaticTurtle/esphome_syslog)
    and switch to ESPHome's built-in syslog + udp components. Also update xl4432
    header to match constructor signature, fix ICACHE_RAM_ATTR deprecation warning,
    add safety return in extractMeterReading, switch to esphome OTA platform,
    remove MQTT in favor of web_server, and update meter config.
    [xl4432.cpp, xl4432_spi_sensor.cpp]
2026-03-22 feat: crack bytes 15-19 scrambling, add packet sniffer mode, add Stages 5-6
    Bytes 15-19 are a GF(2) linear function of consumption bits (binary matrix
    multiplication). Verified 346/346 clean packets (100%). Added packet_sniff
    YAML option to ESPHome component for capturing all meters' raw packets.
    - Add Stage 5: propagation analysis (discovered GF(2) structure via XOR deltas)
    - Add Stage 6: GF(2) matrix extraction, verification, and C code generation
    - Add packet_sniff option to ESPHome sensor (logs all packets, no HA publish)
    - Update PROTOCOL.md with full scrambling algorithm and multi-meter observations
    - Add multi-meter packets to packets.txt (883 total, 5 meters)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
    [xl4432.cpp, xl4432_spi_sensor.cpp]
2026-03-22 feat: add GF(2) packet validation, packet sniffer mode
    Replace the old "2 identical readings" validation with GF(2) linear
    scramble verification. First packet learns the per-meter constant,
    all subsequent packets are validated against it. Any RF bit error in
    meter ID, consumption, or scramble bytes is detected.
    - Add deriveConstant() and validatePacket() to xl4432
    - Add consumption basis vectors (15 x 40-bit) for GF(2) computation
    - Add packet_sniff YAML option for raw packet capture mode
    - Mask last nibble (unreliable Manchester timing drift)
    - Add .gitignore for research files
    [xl4432.cpp, xl4432_spi_sensor.cpp]
2026-03-22 docs: update README files with GF(2) validation and current features
2026-03-22 fix: require 2 consecutive matching constants before confirming
    If the first packet has RF errors, the derived constant is wrong and
    all subsequent valid packets would be rejected. Now the constant must
    be derived identically from 2 consecutive packets before it is locked in.
    [xl4432.cpp]
2026-03-22 docs: update validation flow to reflect 2-packet confirmation
2026-03-22 feat: add GF(2) constant and status logging
    Log the derived constant, reading value, and validation status for
    every packet. RF errors show both the derived and expected constants.
    Tag changed to 'gf2' for easy filtering.
    [xl4432_spi_sensor.cpp]
2026-03-25 feat: single-packet GF(2) validation with full ID basis matrix
    Replace the 2-packet learning approach with direct single-packet
    validation using the cracked OFFSET (0x2CA2C00A20) and 24-bit meter ID
    basis vectors. Every packet is now independently verified — no warm-up
    phase or prior data needed. Add PROTOCOL.md documenting the full
    scrambling algorithm and basis vectors.
    [xl4432.cpp, xl4432_spi_sensor.cpp]
2026-03-25 fix: update OFFSET, ID basis bits 2-7, and meter ID endianness
    Sync code and docs with latest PROTOCOL.md RANSAC results:
    - OFFSET: 0x2CA2C00A20 → 0xDF750DC2C0
    - ID_BASIS bits 2-7: updated from 105/126 RANSAC solve
    - Fix meter ID documented as little-endian → big-endian (matches code)
    [xl4432.cpp]
2026-03-26 Update GF(2) matrix: 24 CONS_BASIS vectors, corrected ID_BASIS bits 2-7
    CONS_BASIS extended from 15 to 24 vectors (bits 0-23, bit 23 = zero).
    Bits 0-16 proven via transition analysis. Bits 17-22 solved via
    GF(2) linear system from 10 high-consumption meters (7/10 consistent).
    ID_BASIS bits 2,3,5,6 corrected via non-circular RANSAC (71/72, 98.6%)
    using 72 two-packet-confirmed meters. Bit 7 confirmed zero.
    OFFSET restored to 0xDF750DC2C0.
    268 platinum meters validate. 68% raw packet pass rate.
    [xl4432.cpp]
2026-03-26 Skip non-standard meters in validation (x40, 3D0C, others)
    Only standard meters (bytes 8-9 = 0x00 0x00) use the proven GF(2) matrix.
    Non-standard meters (x40, 3D0C) share CONS_BASIS but have different
    ID_BASIS/OFFSET. Added PKT_NON_STANDARD status for these.
    [xl4432.cpp, xl4432_spi_sensor.cpp]
2026-03-26 Fix: remove 5579DE from physical verification (it's an x40 meter)
    ID bit 2 no longer physically proven — only supported by RANSAC 71/72.
    Bits 3,5,6 still proven by 93D9E9, 082CD3, 5E2EE8 (all standard).
2026-03-26 Sonata/x40: consumption in liters (÷1000 for m³)
    Byte 9 = 0x40 indicates Arad Sonata ultrasonic meter.
    extractMeterReading now uses ÷1000 for x40, ÷10 for standard.
2026-03-26 ESPHome: TCP server for wireless sniffing (port 4321)
    Streams all received packets in sniff format over TCP, independent of
    sniff mode. Supports up to 3 simultaneous clients. The Android app
    can connect via phone hotspot instead of USB cable.
2026-03-26 TCP server is now a YAML config option (tcp_server: true)
    Off by default. Enable in YAML:
    sensor:
    - platform: xl4432_spi_sensor
    tcp_server: true
    ...
2026-03-26 Document tcp_server option and wireless setup in both READMEs
2026-03-28 LFSR-based validation: replace lookup tables with single seed + 8 submasks
    - Replace 48 hardcoded basis vectors with LFSR generation from seed
    0xA045A72F80 and 8 submask values. Byte 12 vectors kept separate.
    - Handle general alarm flag (byte 4 bit 5) with XOR 0xA8F1156730.
    - Filter reboot packets (byte 4 bit 7) where consumption is invalid.
    - Prepare for per-group byte-7 correction (currently STD only).
    - Non-STD groups fall back to two-packet validation.
    - Verified 877/877 identical results vs old lookup tables on STD packets.
    [xl4432.cpp]
2026-03-28 Byte 12 in LFSR, fix CONS[17,18,22], 3-bit error correction
    - LFSR seed updated to 0x51AAF3D980 (byte 12 bit 0).
    - Removed CONS_HI table — all 64 vectors from single LFSR.
    - 3-bit error correction in validatePacket(): 193K checks, ~4ms on ESP32.
    - Corrected packets get re-extracted reading and published.
    - STD validation: 67% -> 92.8% with error correction.
    [xl4432.cpp]
2026-03-28 Add packet statistics: valid/corrected/invalid counts, log every 10 packets
    [xl4432_spi_sensor.cpp]
2026-03-28 Per-packet status tag [OK/F1/F2/F3/BAD/2PK/NS] in log and TCP output
    - Each packet logged with status: OK=valid, F1/F2/F3=corrected N bits,
    BAD=uncorrectable, 2PK=two-packet, NS=non-standard
    - Corrected packets update hex output before sending to TCP clients
    - TCP clients receive the corrected packet (not the raw errored one)
    - Stats line every 10 packets unchanged
    [xl4432_spi_sensor.cpp]
2026-03-29 ESPHome: unified LFSR model, all groups, 3-bit error correction
    Replaces old STD-only validation (BYTE7_CORRECTION, ALARM_VEC, per-group
    offset) with unified pure LFSR model. Now validates all groups (STD, x40,
    3D0C) with a single code path and universal offset 0x6FF11521E8.
    160 syndrome bits (120 data + 40 scramble) for error correction.
    [xl4432.cpp]
2026-03-29 Remove two-packet references, sync PROTOCOL.md and validator
    Two-packet confirmation removed — unified LFSR model validates every
    packet directly with 3-bit error correction. deriveConstant retained
    for ID recovery only.
2026-03-29 Add syndrome lookup table validator — O(1) error correction via precomputed hash
    Precompute all 1/2/3-bit error syndromes (682K entries) into a hash table.
    Single O(1) lookup replaces nested for-loops. Identical results to brute-force.

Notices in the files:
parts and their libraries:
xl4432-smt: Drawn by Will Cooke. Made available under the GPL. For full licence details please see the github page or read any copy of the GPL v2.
